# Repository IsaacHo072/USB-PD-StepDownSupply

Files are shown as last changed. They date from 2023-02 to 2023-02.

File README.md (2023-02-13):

# USB-PD-StepDownSupply
A USB PD (Sink) DC-DC step-down power supply, requests 15-9V from PD source, provides 5V and 3.3V output.

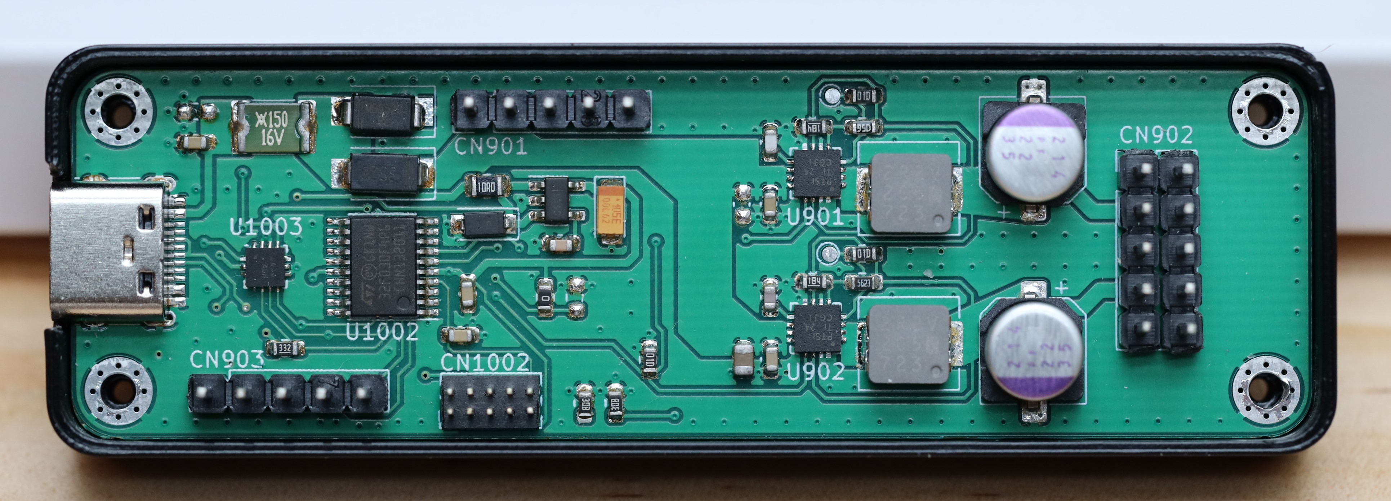
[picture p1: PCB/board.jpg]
Photo of PCB


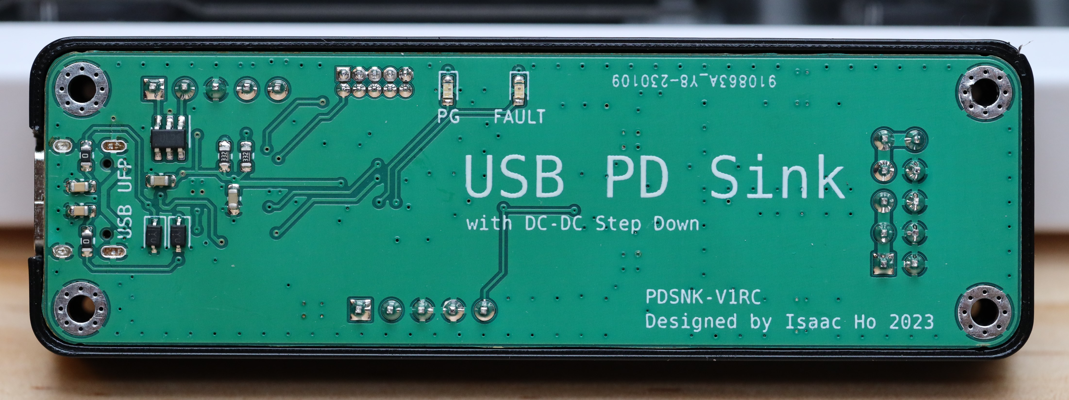
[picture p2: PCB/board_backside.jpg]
Another Photo of PCB


## Components
Uses a FUSB302 and a STM32F030F4P6 for USB PD.
Two TPS62130 for step down.

## Program
A compiled firmware is provided for getting 15-9V from PD source. 
ST-Link, or any SWD programmer could be used for programming. 
Connect the ST-Link connector to CN1002 to download the firmware.

The firmware was modified from [manuelbl/zy12pdn-oss](https://github.com/manuelbl/zy12pdn-oss).

## Issues
This cannot be used with regular USB power supply (non-PD), or USB PD supply with 5V only power output, as TPS62130 cannot output 5V from 5V input. 

To be fixed:
- C1003 have wrong footprint size, 1206 should be used as a 0603 22uF capacitor voltage rating is too low.
- D1002 is bidirectional TVS diode, but if a unidirectional TVS diode is used, the polarity marking is on the wrong side. 
- Some trace could be bigger.

## Cost
The whole board could be made at around a few dollars.

When making 10 boards, each cost:
- FUSB302: $0.7
- STM32F030F4P6: $0.5
- TPS62130: $1*2
- HRO TYPE-C-31-M-12: $0.1
- Other components: $2 at most
- PCB: ~$10 (for 10)

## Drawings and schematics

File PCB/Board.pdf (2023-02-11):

1 | 2 | 3 | 4 | 5 | 6

A

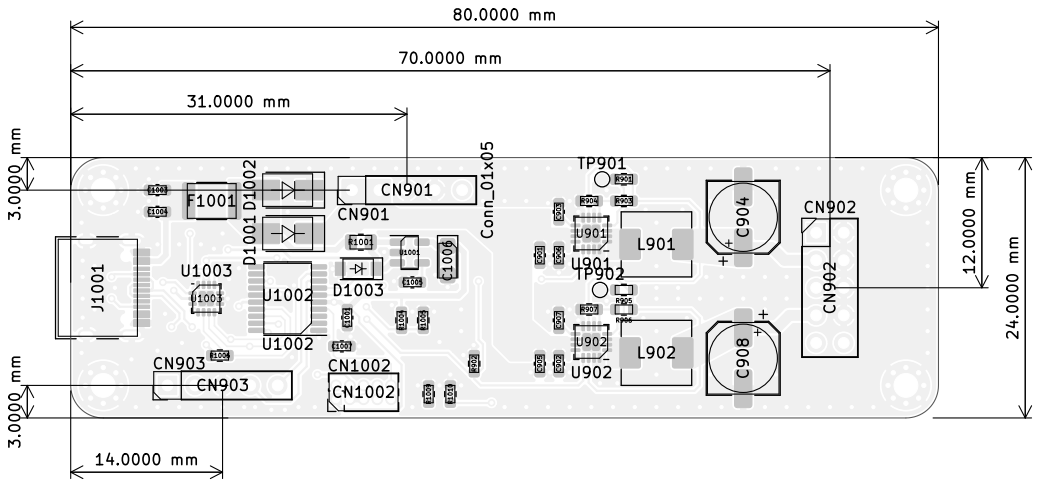
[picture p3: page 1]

1 | 2 | 3 | 4 | 5 | 6

A

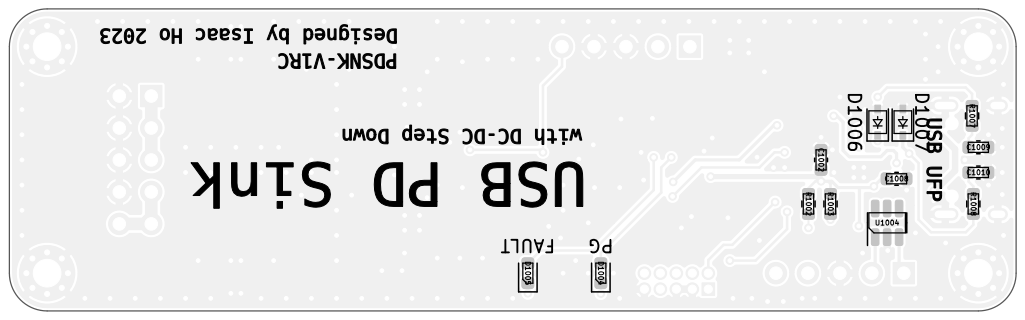
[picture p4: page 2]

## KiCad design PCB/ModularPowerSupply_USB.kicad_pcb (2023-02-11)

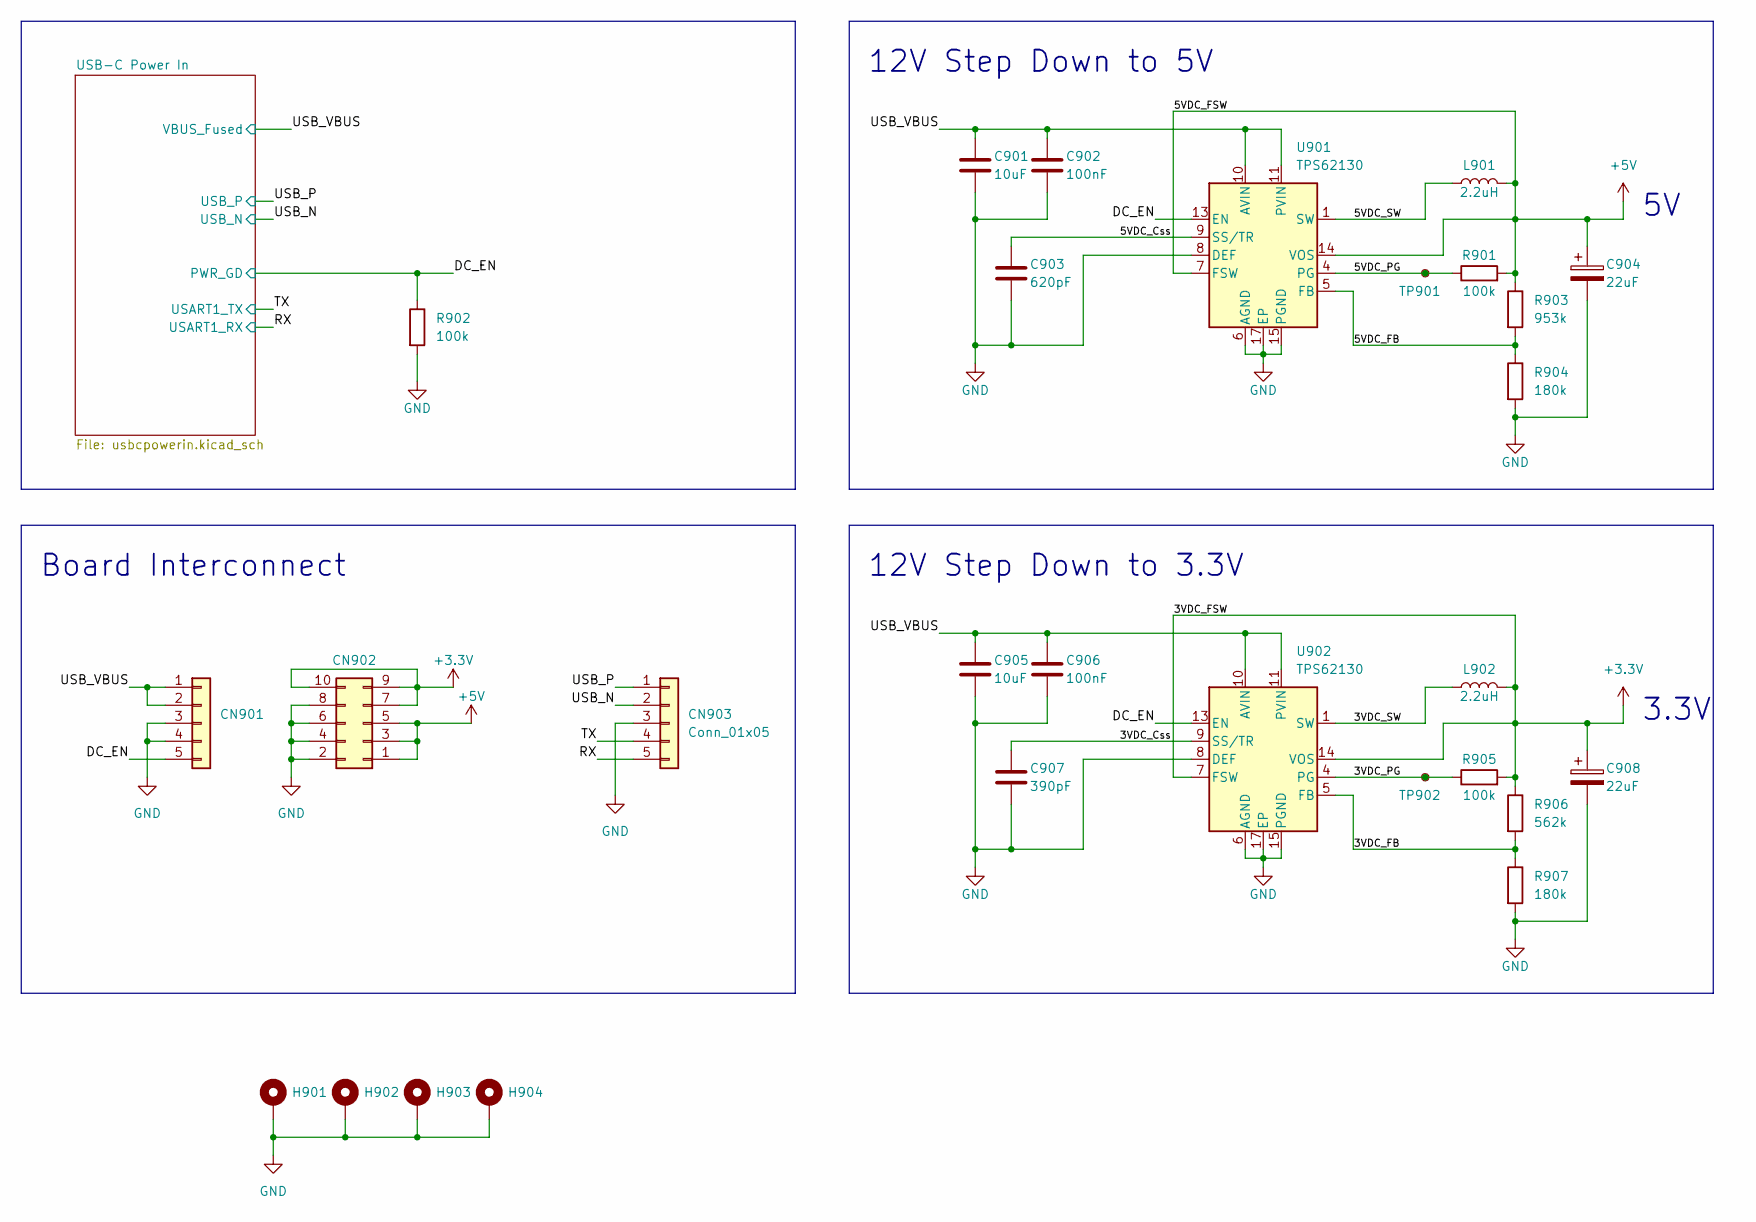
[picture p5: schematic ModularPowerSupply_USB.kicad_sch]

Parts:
C901, C905: 10uF; C_0603_1608Metric
C902, C906: 100nF; C_0603_1608Metric
C903: 620pF; C_0603_1608Metric
C904, C908: 22uF; CP_Elec_6.3x5.9
C907: 390pF; C_0603_1608Metric
CN901, CN903: Conn_01x05; PinHeader_1x05_P2.54mm_Vertical
CN902: Conn_02x05_Odd_Even; PinHeader_2x05_P2.54mm_Vertical
H901, H902, H903, H904: MountingHole_Pad; MountingHole_2.2mm_M2_Pad_Via
L901, L902: 2.2uH; Panasonic Inductor KVP
R901, R902, R905: 100k; R_0603_1608Metric
R903: 953k; R_0603_1608Metric
R904, R907: 180k; R_0603_1608Metric
R906: 562k; R_0603_1608Metric
TP901, TP902: TestPoint_Small; TestPoint_Pad_D1.0mm
U901, U902: TPS62130; VQFN-16-1EP_3x3mm_P0.5mm_EP1.68x1.68mm_ThermalVias

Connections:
+3.3V: C908.1, CN902.7, CN902.9, CN902.10, L902.2, R905.2, R906.1, U902.7 (FSW), U902.14 (VOS)
+5V: C904.1, CN902.1, CN902.3, CN902.5, L901.2, R901.2, R903.1, U901.7 (FSW), U901.14 (VOS)
/3VDC_Css: C907.1, U902.9 (SS/TR)
/3VDC_FB: R906.2, R907.1, U902.5 (FB)
/3VDC_PG: R905.1, TP902.1, U902.4 (PG)
/3VDC_SW: L902.1, U902.1 (SW), U902.2 (SW), U902.3 (SW)
/5VDC_Css: C903.1, U901.9 (SS/TR)
/5VDC_FB: R903.2, R904.1, U901.5 (FB)
/5VDC_PG: R901.1, TP901.1, U901.4 (PG)
/5VDC_SW: L901.1, U901.1 (SW), U901.2 (SW), U901.3 (SW)
/DC_EN: CN901.5, R902.1, U901.13 (EN), U902.13 (EN); also elsewhere on the board
/RX: CN903.5; also elsewhere on the board
/TX: CN903.4; also elsewhere on the board
/USB_N: CN903.2; also elsewhere on the board
/USB_P: CN903.1; also elsewhere on the board
/USB_VBUS: C901.1, C902.1, C905.1, C906.1, CN901.1, CN901.2, U901.10 (AVIN), U901.11 (PVIN), U901.12 (PVIN), U902.10 (AVIN), U902.11 (PVIN), U902.12 (PVIN); also elsewhere on the board
GND: C901.2, C902.2, C903.2, C904.2, C905.2, C906.2, C907.2, C908.2, CN901.3, CN901.4, CN902.2, CN902.4, CN902.6, CN902.8, CN903.3, H901.1, H902.1, H903.1, H904.1, R902.2, R904.2, R907.2, U901.6 (AGND), U901.8 (DEF), U901.15 (PGND), U901.16 (PGND), U901.17 (EP), U902.6 (AGND), U902.8 (DEF), U902.15 (PGND), U902.16 (PGND), U902.17 (EP); also elsewhere on the board

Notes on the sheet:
3.3V
12V Step Down to 5V
12V Step Down to 3.3V
Board Interconnect

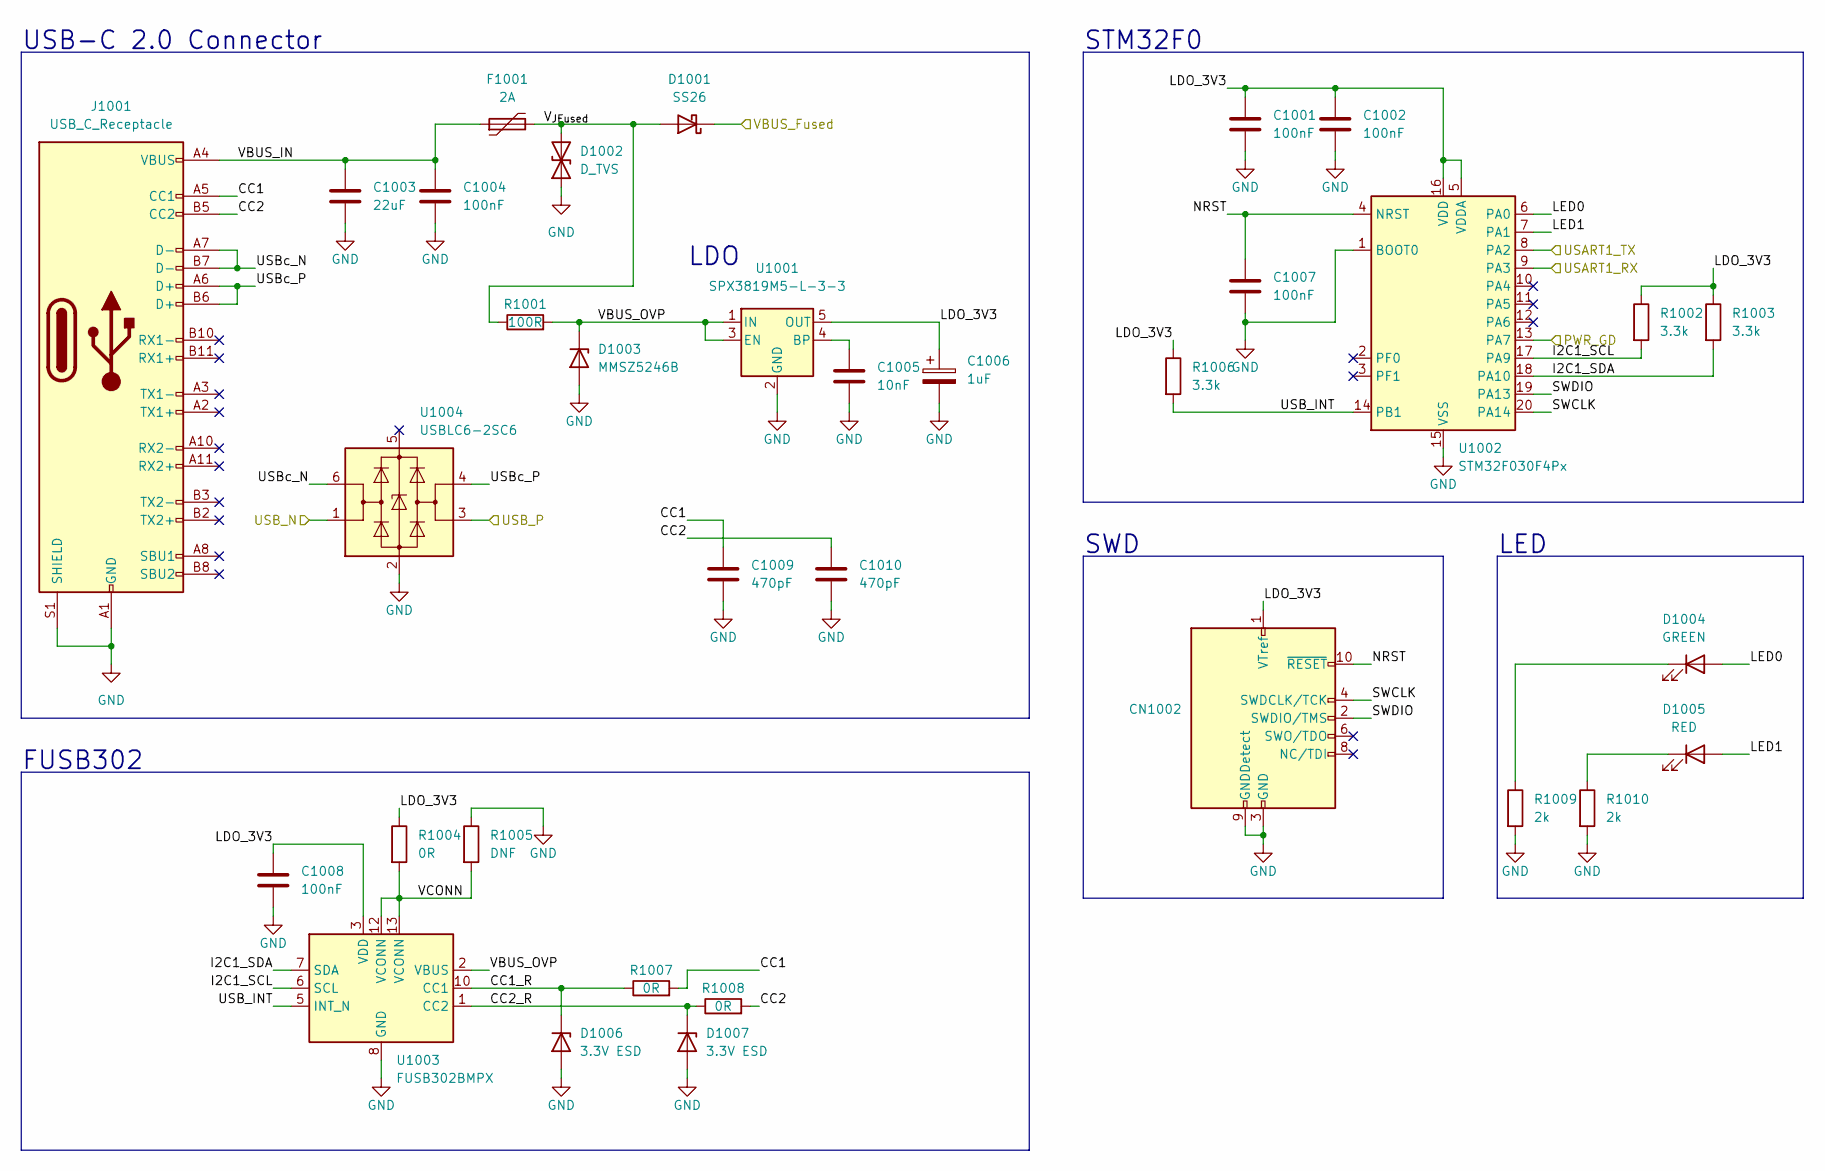
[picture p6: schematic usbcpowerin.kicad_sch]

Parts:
C1001, C1002, C1004, C1007, C1008: 100nF; C_0603_1608Metric
C1003: 22uF; C_0603_1608Metric
C1005: 10nF; C_0603_1608Metric
C1006: 1uF; CP_EIA-3216-18_Kemet-A
C1009, C1010: 470pF; C_0603_1608Metric
CN1002: Conn_ARM_JTAG_SWD_10; PinHeader_2x05_P1.27mm_Vertical
D1001: SS26; D_SMA
D1002: D_TVS; D_SMA
D1003: MMSZ5246B; D_SOD-123
D1004: GREEN; D_0603_1608Metric
D1005: RED; D_0603_1608Metric
D1006, D1007: 3.3V ESD; D_SOD-323
F1001: 2A; Fuse_1812_4532Metric
J1001: USB_C_Receptacle; USB_C_Receptacle_HRO_TYPE-C-31-M-12
R1001: 100R; R_0805_2012Metric
R1002, R1003, R1006: 3.3k; R_0603_1608Metric
R1004, R1007, R1008: 0R; R_0603_1608Metric
R1005: DNF; R_0603_1608Metric
R1009, R1010: 2k; R_0603_1608Metric
U1001: SPX3819M5-L-3-3; SOT-23-5
U1002: STM32F030F4Px; TSSOP-20_4.4x6.5mm_P0.65mm
U1003: FUSB302BMPX; WQFN-14-1EP_2.5x2.5mm_P0.5mm_EP1.45x1.45mm
U1004: USBLC6-2SC6; SOT-23-6

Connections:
/DC_EN: U1002.13 (PA7); also elsewhere on the board
/RX: U1002.9 (PA3); also elsewhere on the board
/TX: U1002.8 (PA2); also elsewhere on the board
/USB-C Power In/CC1: C1009.1, J1001.A5 (CC1), R1007.2
/USB-C Power In/CC1_R: D1006.1 (K), R1007.1, U1003.10 (CC1), U1003.11 (CC1)
/USB-C Power In/CC2: C1010.1, J1001.B5 (CC2), R1008.2
/USB-C Power In/CC2_R: D1007.1 (K), R1008.1, U1003.1 (CC2), U1003.14 (CC2)
/USB-C Power In/I2C1_SCL: R1002.2, U1002.17 (PA9), U1003.6 (SCL)
/USB-C Power In/I2C1_SDA: R1003.2, U1002.18 (PA10), U1003.7 (SDA)
/USB-C Power In/LDO_3V3: C1001.1, C1002.1, C1006.1, C1008.1, CN1002.1 (VTref), R1002.1, R1003.1, R1004.1, R1006.1, U1001.5 (OUT), U1002.5 (VDDA), U1002.16 (VDD), U1003.3 (VDD), U1003.4 (VDD)
/USB-C Power In/LED0: D1004.2 (A), U1002.6 (PA0)
/USB-C Power In/LED1: D1005.2 (A), U1002.7 (PA1)
/USB-C Power In/NRST: C1007.1, CN1002.10 (~RESET), U1002.4 (NRST)
/USB-C Power In/SWCLK: CN1002.4 (SWDCLK/TCK), U1002.20 (PA14)
/USB-C Power In/SWDIO: CN1002.2 (SWDIO/TMS), U1002.19 (PA13)
/USB-C Power In/USB_INT: R1006.2, U1002.14 (PB1), U1003.5 (INT_N)
/USB-C Power In/USBc_N: J1001.A7 (D-), J1001.B7 (D-), U1004.6 (I/O1)
/USB-C Power In/USBc_P: J1001.A6 (D+), J1001.B6 (D+), U1004.4 (I/O2)
/USB-C Power In/VBUS_IN: C1003.1, C1004.1, F1001.1, J1001.A4 (VBUS), J1001.A9 (VBUS), J1001.B4 (VBUS), J1001.B9 (VBUS)
/USB-C Power In/VBUS_OVP: D1003.1 (K), R1001.2, U1001.1 (IN), U1001.3 (EN), U1003.2 (VBUS)
/USB-C Power In/VCONN: R1004.2, R1005.2, U1003.12 (VCONN), U1003.13 (VCONN)
/USB-C Power In/V_{JFused}: D1001.2 (A), D1002.2 (A2), F1001.2, R1001.1
/USB_N: U1004.1 (I/O1); also elsewhere on the board
/USB_P: U1004.3 (I/O2); also elsewhere on the board
/USB_VBUS: D1001.1 (K); also elsewhere on the board
GND: C1001.2, C1002.2, C1003.2, C1004.2, C1005.2, C1006.2, C1007.2, C1008.2, C1009.2, C1010.2, CN1002.3 (GND), CN1002.5 (GND), CN1002.9 (GNDDetect), D1002.1 (A1), D1003.2 (A), D1006.2 (A), D1007.2 (A), J1001.A1 (GND), J1001.A12 (GND), J1001.B1 (GND), J1001.B12 (GND), J1001.S1 (SHIELD), R1005.1, R1009.2, R1010.2, U1001.2 (GND), U1002.1 (BOOT0), U1002.15 (VSS), U1003.8 (GND), U1003.9 (GND), U1003.15 (GND), U1004.2 (GND); also elsewhere on the board
unnamed: C1005.1, U1001.4 (BP)
unnamed: D1004.1 (K), R1009.1
unnamed: D1005.1 (K), R1010.1

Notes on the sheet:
STM32F0
FUSB302
LDO
LED
SWD
USB-C 2.0 Connector

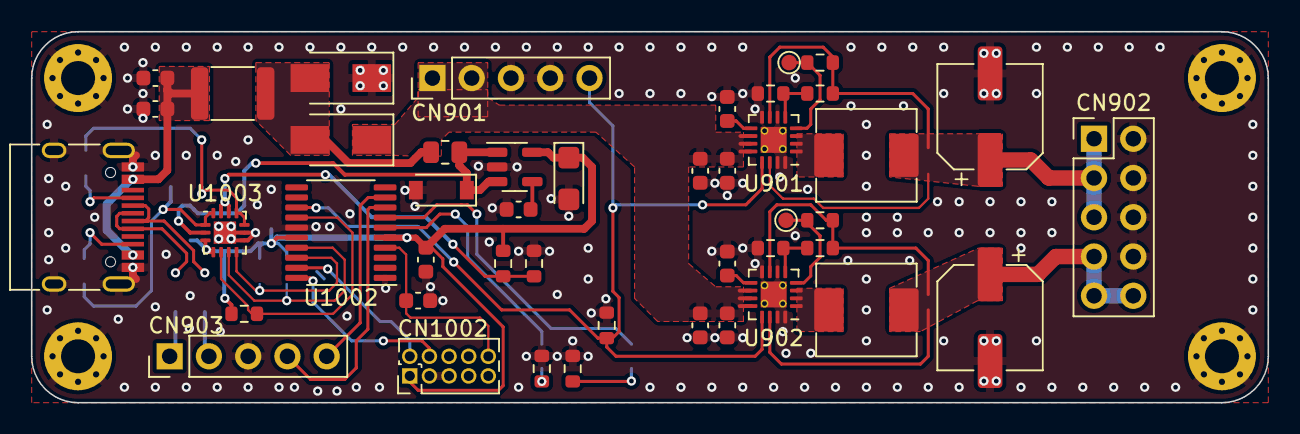
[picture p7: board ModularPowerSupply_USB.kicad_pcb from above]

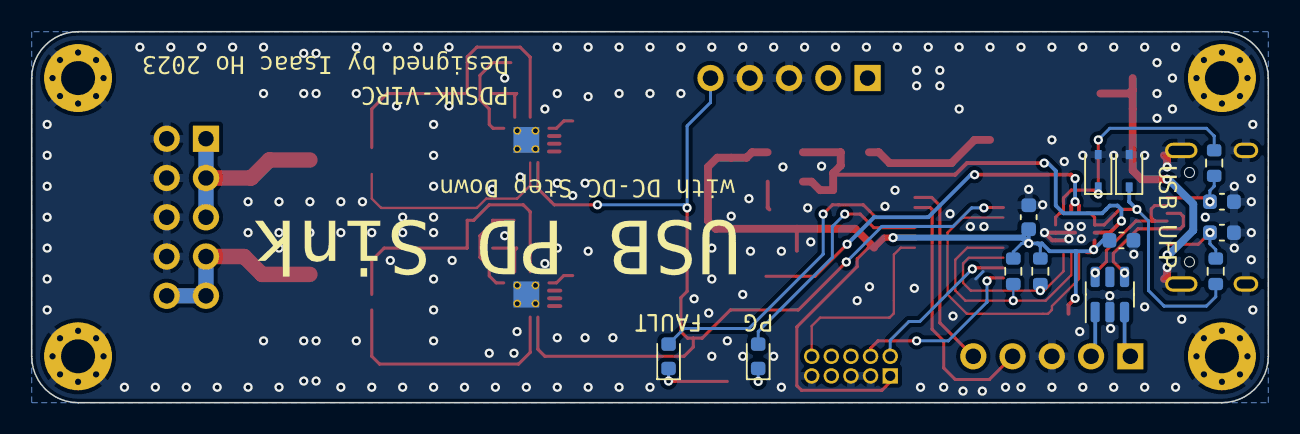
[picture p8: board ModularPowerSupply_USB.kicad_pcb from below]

Board: 2 copper layers, 80.0 x 24.0 mm, 66 parts (17 on the bottom side), 39 nets.

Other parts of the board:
kibuzzard-63BACD81: G***; kibuzzard-63BACD81
kibuzzard-63BACDB6: G***; kibuzzard-63BACDB6
kibuzzard-63BACE7D: G***; kibuzzard-63BACE7D
kibuzzard-63BACF17: G***; kibuzzard-63BACF17

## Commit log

2023-02-11 Initial Release
    [ModularPowerSupply_USB.kicad_pcb, ModularPowerSupply_USB.kicad_sch, usbcpowerin.kicad_sch]
2023-02-11 Modified schematic
    changed C1003 size to 1206
    flipped D1002 around
    [usbcpowerin.kicad_sch]
2023-02-13 Create firmware (Request up to 15V).elf
    This firmware request up to 15V from the power source, if 15V is not available then it request 12V, then 9V, vice versa.
